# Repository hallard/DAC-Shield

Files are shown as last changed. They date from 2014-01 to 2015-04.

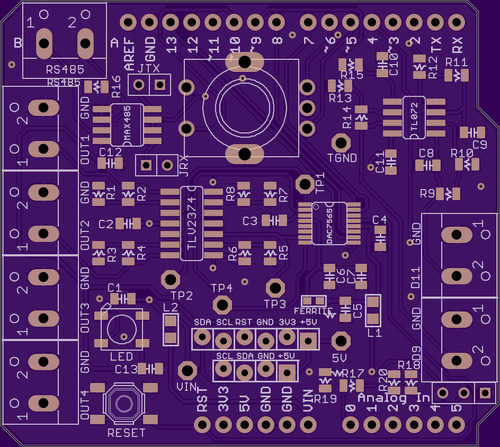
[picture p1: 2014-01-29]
dac-shield-top.png

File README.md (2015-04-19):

0-10V DAC / ADC / RS485 and OLED Arduino Shield
===============================================

This is a simple board to be able to 
- Generate 4 0-10V analog output to drive industrial devices
- 2 0-10V analog input (unprotected) 
- A RS485 Driver (use RX/TX of Arduino)
- 2 I2C Oled connector (Adafruit or Tindie Oled)
- 1 Rotary Encoder
- 1 WS2812B RGB Led

<strike>This is a proto board, I've just ordered one on OSHPark, will put 
more details once received and tested</strike> This shield has been fully tested and it's working fine on all features. 
The only problem was my bad datasheet reading, the DAC7565 output from the chip are not 0V 5V as I expected but 0V 2.5V (internal VREF) So as I multiply ouput per 2, the output for these 4 outputs are 0V-5V not 0V-10V, you can change the multiplier by changing resitor R2/R4/R6/R8 from 10K to 30K.
Also TL072 are not working well with single rail supply for PWM to DAC conversion at low level (says from 0V to 1V), I replaced them
by LM358 (same package) but more suited for single rail supply.

I wrote an Arduino Library to drive the DAC7565 [here][3]

Check out news and other projects on my [blog][4]

Detailed Description
====================

Everything will be documented on my [blog][4]

**Schematic**  
schematic

**Board**  
board

top&nbsp;&nbsp;bottom

[3]: https://github.com/hallard/DAC7565
[4]: http://hallard.me

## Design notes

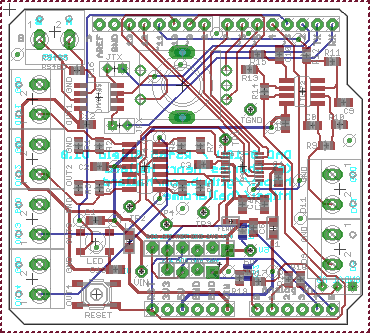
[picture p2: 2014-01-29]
dac-shield-brd.png

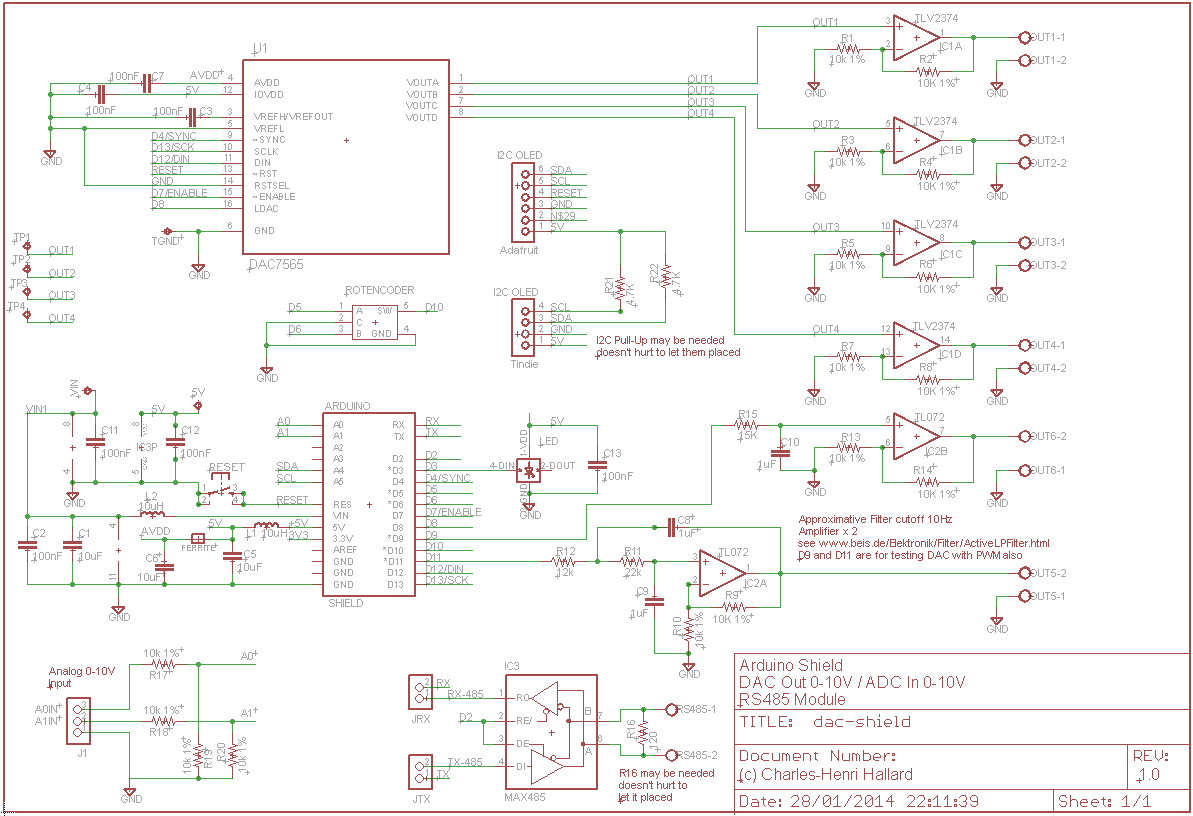
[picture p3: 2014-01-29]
dac-shield-sch.png

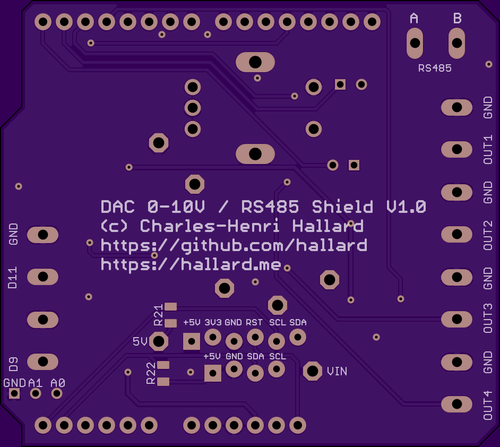
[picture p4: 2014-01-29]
dac-shield-bottom.png

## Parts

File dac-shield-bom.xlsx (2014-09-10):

Qty | Value | Device | Package | Parts | Description | MPN | PACKAGE | SUPPLIER
7 |  | Clamp Connector | W237-102 | OUT1, OUT2, OUT3, OUT4, OUT5, OUT6, RS485 | WAGO SCREW CLAMP
1 |  | Ferrite | _0603 | FERRITE | Ferrite Bead
1 |  | Rotary Encoder | 5P-13.75X11.7X6.5H | ROTENCODER | Rotary Encode With Switch
1 |  | Tactile Switch | SW_TACT_SMALL | RESET | Switch
7 | 100nF | CAP0805-CAP | 0805-CAP | C2, C3, C4, C7, C11, C12, C13 | Capacitor
6 | 10K 1% | RESISTOR0805-RES | 0805-RES | R2, R4, R6, R8, R9, R14 | Resistor
10 | 10k 1% | RESISTOR0805-RES | 0805-RES | R1, R3, R5, R7, R10, R13, R17, R18, R19, R20 | Resistor
3 | 10uF | CAP0805-CAP | 0805-CAP | C1, C5, C6 | Capacitor
2 | 10uH | INDUCTOR_0805 | _0805 | L1, L2 | Inductors
1 | 120 | RESISTOR0805-RES | 0805-RES | R16 | Resistor
1 | 12k | RESISTOR0805-RES | 0805-RES | R12 | Resistor
1 | 15K | RESISTOR0805-RES | 0805-RES | R15 | Resistor
3 | 1uF | CAP0805-CAP | 0805-CAP | C8, C9, C10 | Capacitor
1 | 22k | RESISTOR0805-RES | 0805-RES | R11 | Resistor
2 | 4.7K | RESISTOR0805-RES | 0805-RES | R21, R22 | Resistor
1 | DAC7565 | DAC7565IAPW | SOP65P640X120-16N | U1 | DAC | DAC7565IAPW | TSSOP-16 | Texas Instruments
1 | MAX485 | MAX485CSA | SO08 | IC3 | RS485 TRANSEIVER | MAX485CSA |  | MAXIM
1 | TL072 | TL072D | SO08 | IC2 | DUAL OP AMP
1 | TLV2374 | LM324D | SO14 | IC1 | QUAD OP AMP
1 | WS2812B | WS2812B | WS2812B / 4 PINS Version | LED

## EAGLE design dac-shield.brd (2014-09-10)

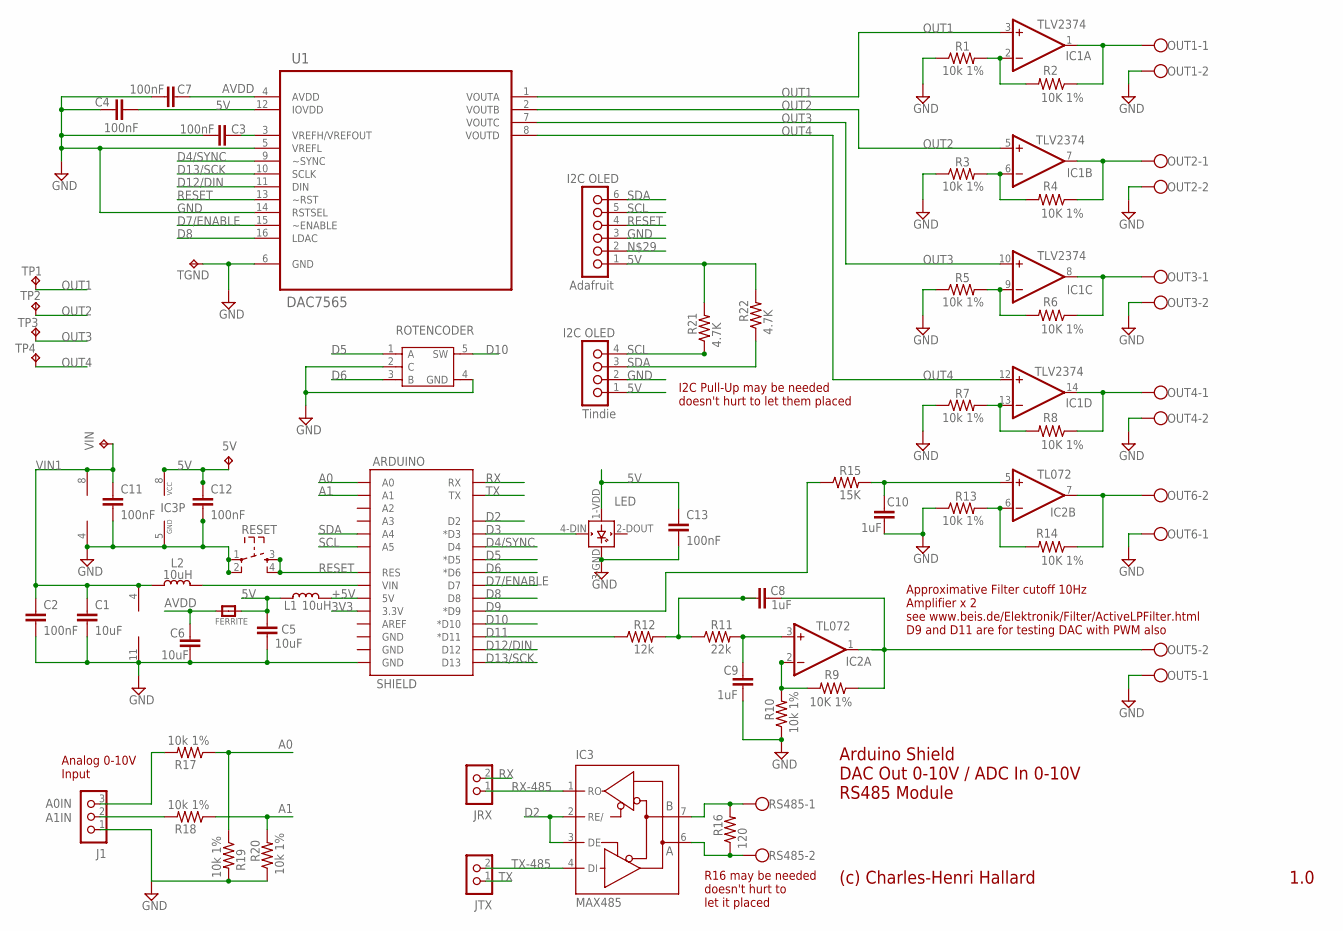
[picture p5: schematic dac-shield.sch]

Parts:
5V: TPPAD1-13; P1-13
ARDUINO: SHIELD; DUEMILANOVE_SHIELD_NOHOLES
C1, C5, C6: 10uF; 0805-CAP
C2, C3, C4, C7, C11, C12, C13: 100nF; 0805-CAP
C8, C9, C10: 1uF; 0805-CAP
FERRITE: FERRITE_0603; _0603
IC1: TLV2374; SO14
IC2: TL072; SO08
IC3: MAX485; SO08
J1: CON_HEADER_1X03-PTH; M1X3
JRX: CON_HEADER_1X02-PTH; M1X2
JTX: CON_HEADER_1X02-PTH; M1X2
L1, L2: 10uH; _0805
LED: WS2812B
OUT1, OUT2, OUT3, OUT4, OUT5, OUT6: CON-CLAMP-2; W237-102
R1, R3, R5, R7, R10, R13, R17, R18, R19, R20: 10k 1%; 0805-RES
R2, R4, R6, R8, R9, R14: 10K 1%; 0805-RES
R11: 22k; 0805-RES
R12: 12k; 0805-RES
R15: 15K; 0805-RES
R16: 120; 0805-RES
R21, R22: 4.7K; 0805-RES
RESET: SW_TACT_4P; SW_TACT_SMALL
ROTENCODER: ROTARY-ENCODE-5P; 5P-13.75X11.7X6.5H
RS485: CON-CLAMP-2; W237-102
TGND: TPPAD1-13; P1-13
TP1, TP2, TP3, TP4: TPPAD1-13; P1-13
U1: DAC7565; SOP65P640X120-16N
U$1: OLED_I2C_ADAFRUIT; 1X06_LOCK
U$2: OLED_I2C_TINDIE; 1X04_LOCK
VIN: TPPAD1-13; P1-13

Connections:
3V3: ARDUINO.3.3V
5V: 5V.TP, C4.1, C5.1, C12.1, C13.1, FERRITE.1, IC3.8 (VCC), L1.1, LED.1-VDD (VDD), R21.2, R22.2, U1.12 (IOVDD), U$1.1 (VIN), U$2.1 (VCC)
+5V: ARDUINO.5V, L1.2
A0: ARDUINO.A0, R17.1, R19.1
A0IN: J1.3, R17.2
A1: ARDUINO.A1, R18.1, R20.2
A1IN: J1.2, R18.2
AVDD: C6.2, C7.1, FERRITE.2, U1.4 (AVDD)
D2: ARDUINO.D2, IC3.2 (RE/), IC3.3 (DE)
D3: ARDUINO.D3 (*D3), LED.4-DIN (DIN)
D4/SYNC: ARDUINO.D4, U1.9 (~SYNC)
D5: ARDUINO.D5 (*D5), ROTENCODER.1 (A)
D6: ARDUINO.D6 (*D6), ROTENCODER.3 (B)
D7/ENABLE: ARDUINO.D7, U1.15 (~ENABLE)
D8: ARDUINO.D8, U1.16 (LDAC)
D9: ARDUINO.D9 (*D9), R15.1
D10: ARDUINO.D10 (*D10), ROTENCODER.5 (SW)
D11: ARDUINO.D11 (*D11), R12.1
D12/DIN: ARDUINO.D12, U1.11 (DIN)
D13/SCK: ARDUINO.D13, U1.10 (SCLK)
GND: ARDUINO.GND@0 (GND), C1.2, C2.2, C3.2, C4.2, C5.2, C6.1, C7.2, C9.1, C10.1, C11.2, C12.2, C13.2, IC1.11 (V-), IC2.4 (V-), IC3.5 (GND), J1.1, LED.3-GND (GND), OUT1.2, OUT2.2, OUT3.2, OUT4.2, OUT5.1, OUT6.1, R1.1, R3.1, R5.1, R7.1, R10.1, R13.1, R19.2, R20.1, RESET.1, RESET.2, ROTENCODER.2 (C), ROTENCODER.4 (GND), TGND.TP, U1.5 (VREFL), U1.6 (GND), U1.14 (RSTSEL), U$1.3 (GND), U$2.2 (GND)
unnamed: IC1.6 (-IN), R3.2, R4.2
unnamed: IC1.2 (-IN), R1.2, R2.2
unnamed: IC1.1 (OUT), OUT1.1, R2.1
unnamed: ARDUINO.VIN, L2.2
unnamed: IC2.2 (-IN), R9.2, R10.2
unnamed: C3.1, U1.3 (VREFH/VREFOUT)
unnamed: IC2.6 (-IN), R13.2, R14.2
unnamed: C8.2, IC2.1 (OUT), OUT5.2, R9.1
unnamed: IC1.7 (OUT), OUT2.1, R4.1
unnamed: IC1.9 (-IN), R5.2, R6.2
unnamed: IC1.8 (OUT), OUT3.1, R6.1
unnamed: IC1.13 (-IN), R7.2, R8.2
unnamed: IC1.14 (OUT), OUT4.1, R8.1
unnamed: C8.1, R11.1, R12.2
unnamed: C9.2, IC2.3 (+IN), R11.2
unnamed: IC2.7 (OUT), OUT6.2, R14.1
unnamed: C10.2, IC2.5 (+IN), R15.2
unnamed: IC3.7 (B), R16.2, RS485.1
unnamed: IC3.6 (A), R16.1, RS485.2
OUT1: IC1.3 (+IN), TP1.TP, U1.1 (VOUTA)
OUT2: IC1.5 (+IN), TP2.TP, U1.2 (VOUTB)
OUT3: IC1.10 (+IN), TP3.TP, U1.7 (VOUTC)
OUT4: IC1.12 (+IN), TP4.TP, U1.8 (VOUTD)
RESET: ARDUINO.RES, RESET.3, RESET.4, U1.13 (~RST), U$1.4 (RST)
RX: ARDUINO.RX, JRX.2
RX-485: IC3.1 (RO), JRX.1
SCL: ARDUINO.A5, R21.1, U$1.5 (SCL), U$2.4 (SCL)
SDA: ARDUINO.A4, R22.1, U$1.6 (SDA), U$2.3 (SDA)
TX: ARDUINO.TX, JTX.1
TX-485: IC3.4 (DI), JTX.2
VIN1: C1.1, C2.1, C11.1, IC1.4 (V+), IC2.8 (V+), L2.1, VIN.TP

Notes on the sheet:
Approximative Filter cutoff 10Hz Amplifier x 2 see www.beis.de/Elektronik/Filter/ActiveLPFilter.html D9 and D11 are for testing DAC with PWM also
I2C Pull-Up may be needed doesn't hurt to let them placed
Analog 0-10V Input
(c) Charles-Henri Hallard
1.0
Arduino Shield DAC Out 0-10V / ADC In 0-10V RS485 Module
R16 may be needed doesn't hurt to let it placed

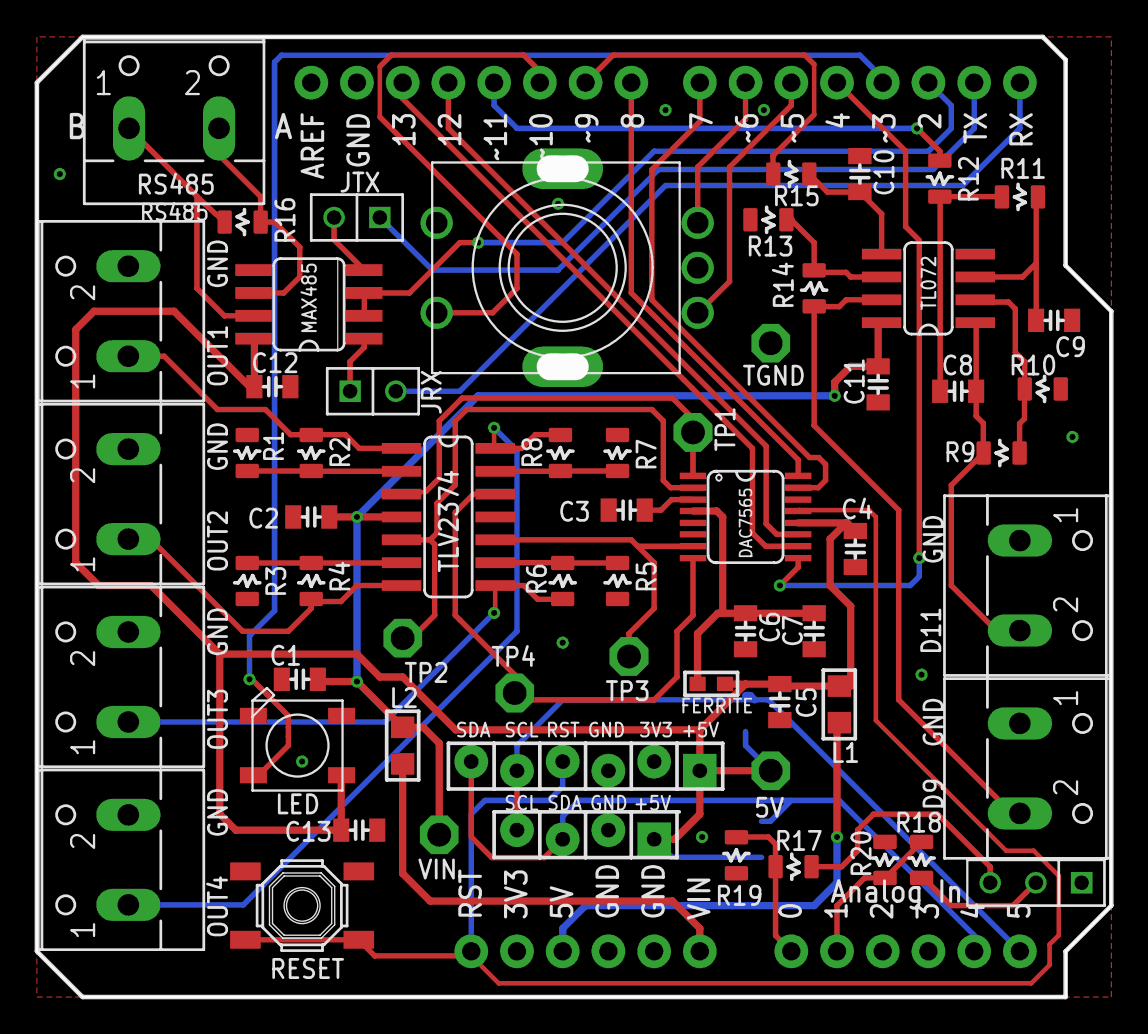
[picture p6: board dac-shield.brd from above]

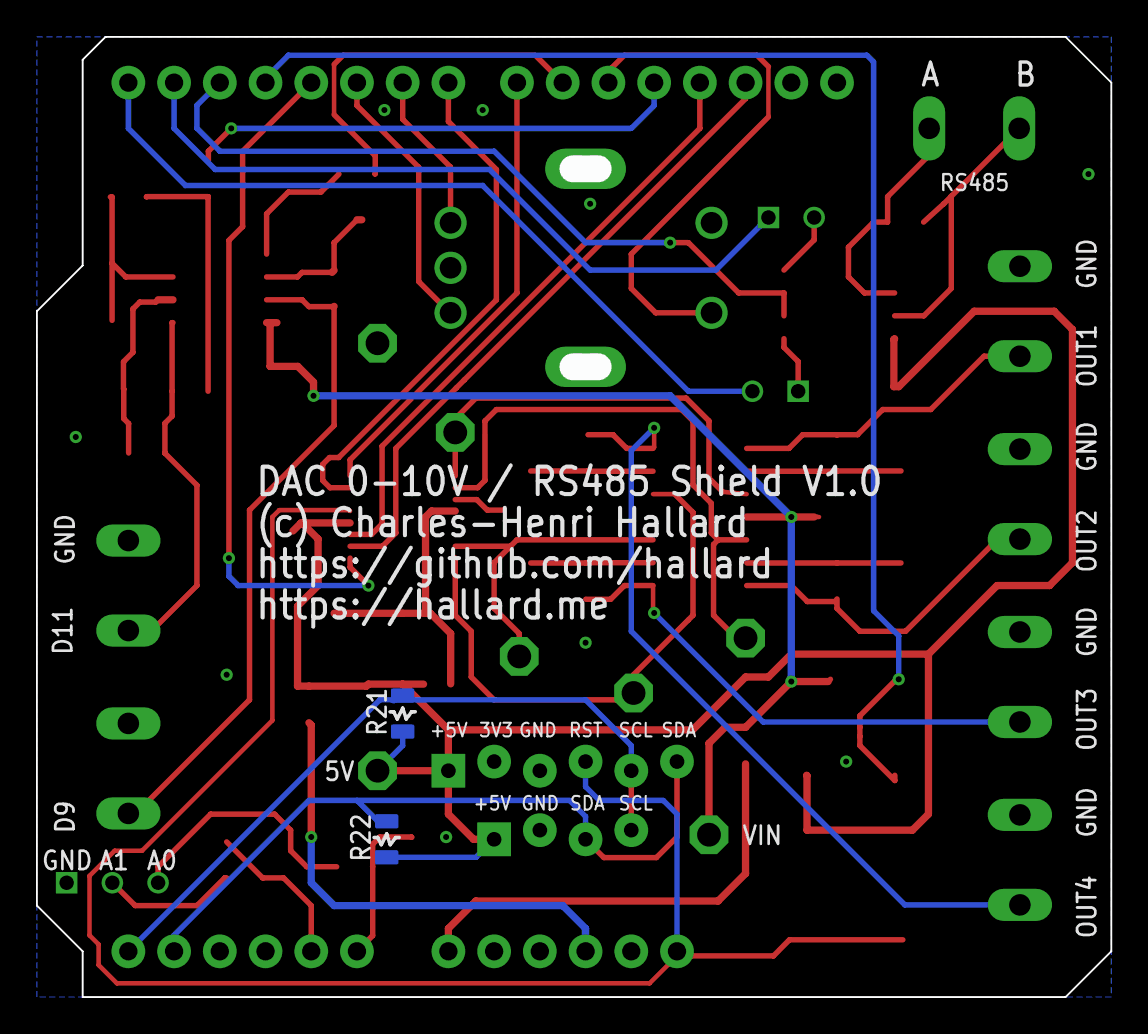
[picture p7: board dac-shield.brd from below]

Board: 2 copper layers, 59.7 x 53.3 mm, 65 parts (2 on the bottom side), 51 nets.

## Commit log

2014-01-29 Image Link Case change
2014-01-29 Image Link Case Error
2014-09-10 Changed Via Mask
    Changed Via Stop Limit to avoid copper on via
    [dac-shield.brd]
2014-09-10 Updated to Eagle 6.6
    [dac-shield.sch]
2015-04-19 Added Testing results and Arduino Lib

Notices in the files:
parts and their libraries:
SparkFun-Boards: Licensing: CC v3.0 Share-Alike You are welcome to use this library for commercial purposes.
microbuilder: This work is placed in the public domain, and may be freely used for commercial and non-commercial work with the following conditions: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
